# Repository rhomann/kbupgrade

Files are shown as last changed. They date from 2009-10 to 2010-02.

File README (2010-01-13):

|
| Keyboard Upgrade -- A generic open source firmware for
|                     homebrew computer keyboard controllers
|                     based on Atmel AVR microcontrollers.
|
| E-Mail: kbupgrade [at] gmx.net

_           _
=== What? ===

Have a PS/2 keyboard, but your brand new computer only supports USB?
Your PS/2-to-USB converter does its job only half-hearted?
Or do you have a keyboard never intended to work on a PC or Mac, but still want
to use it?

Then Keyboard Upgrade is for you! Build your own USB keyboard controller and
let the free Keyboard Upgrade firmware blow some life into it! Multiple
user-defined key maps can be uploaded to your controller and switched at any
time, turning your keyboard into a Dvorak or Colemak or any other layout
keyboard in hardware.

This open source firmware was designed for use on homebrew keyboard controllers
based on Atmel AVR microcontrollers--in particular, the ATMEGA series.
Currently, these keyboards are supported:

- IBM Model M (1391401 and compatibles)
- IBM Model M Mini (1392934 and compatibles)
- IBM M4-1 (without trackpoint)
- IBM Model M 122-key terminal keyboards (1390702 and compatibles)

Schematics are included. Support for new controller designs can be added fairly
easily by re-using a common set of source code files.

_                 _
=== Lawyer Mode ===

Copyright (C) 2009, 2010  Robert Homann.

The Keyboard Upgrade package is published under the terms of the
GNU General Public License Version 2.0 (or any later version),
GNU GPL for short.
See the file COPYING distributed with this package for the license terms.

Keyboard Upgrade makes use of the V-USB driver by
Objective Development Software GmbH.
Their driver is licensed under the terms of the GNU GPL as long as it is not
used commercially. For the exact license terms, please see

  http://www.obdev.at/products/vusb/

or the License.txt file in the directory containing the V-USB version shipped
with this software package.

Keyboard Upgrade also makes use of a modified version of the
BootloadHID USB boot loader by Objective Development Software GmbH.
BootloadHID is licensed under the terms of the GNU GPL as long as it is not
used commercially. For the exact license terms, please see

  http://www.obdev.at/products/vusb/bootloadhid.html
  http://www.obdev.at/products/vusb/

or the License.txt file in the directory containing the BootloadHID version
shipped with this software package.

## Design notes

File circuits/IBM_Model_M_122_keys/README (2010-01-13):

There are two circuit designs for IBM Model M 122-key terminal keyboards
in this directory: one with LED support (schematic.pdf), and a simpler
circuit without LEDs (simple.pdf). Both have been made with KiCad.

If your terminal keyboards does not have LEDs and you are not planning to
add some, it is recommended to stick with the simpler design, which is
also a bit cheaper than the LED-enabled version.

Jumper KM0 is on PD7 (pin 21) in the version with LED support, and on
PD3 (pin 17) in the simplified version.

Thanks to Specter_57 for providing the keyboard matrix information.

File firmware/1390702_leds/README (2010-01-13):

This is the firmware for IBM Model M 122-key terminal keyboards such as the IBM
1390702 with LED support. Take a look at the simplified version without LED
support if your keyboard doesn't have LEDs.

Suitable PCBs:
- Circuits are included (circuits/IBM_Model_M_122_keys/schematic.pdf).

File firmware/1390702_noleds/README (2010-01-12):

This is the firmware for IBM Model M 122-key terminal keyboards such as the IBM
1390702. Since the 1390702 does not have LEDs, there is no support for LEDs in
this firmware. There is another version with LED support, but the circuit for
that one is a bit more complicated.

Suitable PCBs:
- Circuits are included (circuits/IBM_Model_M_122_keys/simple.pdf).

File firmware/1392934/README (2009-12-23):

This is the firmware for IBM Model M Space Saving keyboards (also known as
"Space Saver" or "Model M Mini"). The firmware has been tested with a
1391472 and a 1392934.

Suitable PCBs:
- RUMP by Chris Lee (see http://mg8.org/rump/)
- Dulcimer by Ronald Schaten (see http://www.schatenseite.de/dulcimer.html)

Notes:
- Using this firmware instead of the version for the full-size version is
  advantageous because (1) the keyboard layout is sparser than on the full-size
  version, resulting in fewer chances for ghost keys; and (2) it gives you
  three more free I/O pins on the microcontroller (pins 18, 19, and 20) because
  there are no LEDs on the keyboard.
- If you plan to add LEDs to your Space Saver, consider using the firmware for
  the full-size version for a start. Adding LED support to the the version in
  this directory, however, is trivial and can be implemented upon request.
  Please contact the package author if you want this.

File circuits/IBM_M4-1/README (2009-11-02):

This is a circuit design for an IBM M4-1 keyboard (made with KiCad).

There are at least two different versions of the original PCB. Their dimensions
are very similar, but otherwise they are quite different. The problem is that
they have different connectors for attaching the keyboard matrix, LEDs, and
mouse buttons to the board, so you need to check your keyboard before building
the replacement PCB.

One version has a 19-pin connector and a 9-pin connector for the keyboard
matrix, plus a separate 4-pin connector for the LEDs, and another 4-pin
connecter for connecting the mouse buttons (only three traces used). Such a PCB
was found inside a 1379590 made by Lexmark (1994).

The other version has a 22-pin connector and a 13-pin connector for the
keyboard matrix. Three of the traces on the 22-pin connector are used for the
two mouse buttons and their GND, and four traces on the 13-pin connector are
used for the LEDs and their common GND (or +5V?). The PCB was found inside a
84G2524 made by Unicomp (1999), which also had an unused 4-pin connector
(mounted in the same place as the one for the mouse buttons on the Lexmark
model).

Jumper KM0 is on PD3 (pin 17).

Confirmed to work with the following keyboard models:

- 1379590 (Lexmark 1994)
- 84G2524 (Unicomp 1999)

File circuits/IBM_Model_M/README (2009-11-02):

There are two alternative circuit designs for IBM Model M keyboards
in this directory, suitable for various IBM models.

One of the designs comes from the RUMP project by Chris Lee
(see http://mg8.org/rump/), made with Eagle.
The other one comes from the Dulcimer project by Ronald Schaten
(see http://www.schatenseite.de/dulcimer.html), made with KiCad.

Jumper KM0 is on PD7 (pin 21).

Confirmed to work with the following keyboard models:

Classic, clicky Model M
- 1391401

Model M Mini (Space Saver)
- 1391472
- 1392934

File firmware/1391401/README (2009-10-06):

This is the firmware for IBM Model M keyboards. It has been tested with a
1391401, but may also work with other, similar IBM models.

Suitable PCBs:
- RUMP by Chris Lee (see http://mg8.org/rump/)
- Dulcimer by Ronald Schaten (see http://www.schatenseite.de/dulcimer.html)

Notes:
- When using RUMP, you may want to add three resistors and a 4-pin connector
  for the LEDs (see the Dulcimer PCB on how to connect).
- If you have a Model M Mini (aka Space Saver), consider using the firmware in
  the 1392934 directory instead.

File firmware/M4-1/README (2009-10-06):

This is the firmware for IBM M4-1 keyboards. It also works on the Unicomp
versions, at least on those with a blue IBM logo (tested on a 84G2524 model
from 1999).

Suitable PCBs:
- Circuit is included.

Notes:
- The circuit does not support the trackpoint yet, but is prepared to do so in
  the future. For this reason, port A on the ATMEGA is not utilized since the
  pins on this port can be configured as inputs for the ATMEGA's A/D
  converters.
- For an M4 (the one without the trackpoint) it should be possible to make a
  specialized version that does not attempt to use the trackpoint and mouse
  buttons. The circuit for that model would be a bit simpler since the pins
  used for trackpoint axes and mouse buttons could be used for the keyboard
  rows. This saves one shift register and 8 diodes (not much saved in terms of
  money, but in terms of PCB space).

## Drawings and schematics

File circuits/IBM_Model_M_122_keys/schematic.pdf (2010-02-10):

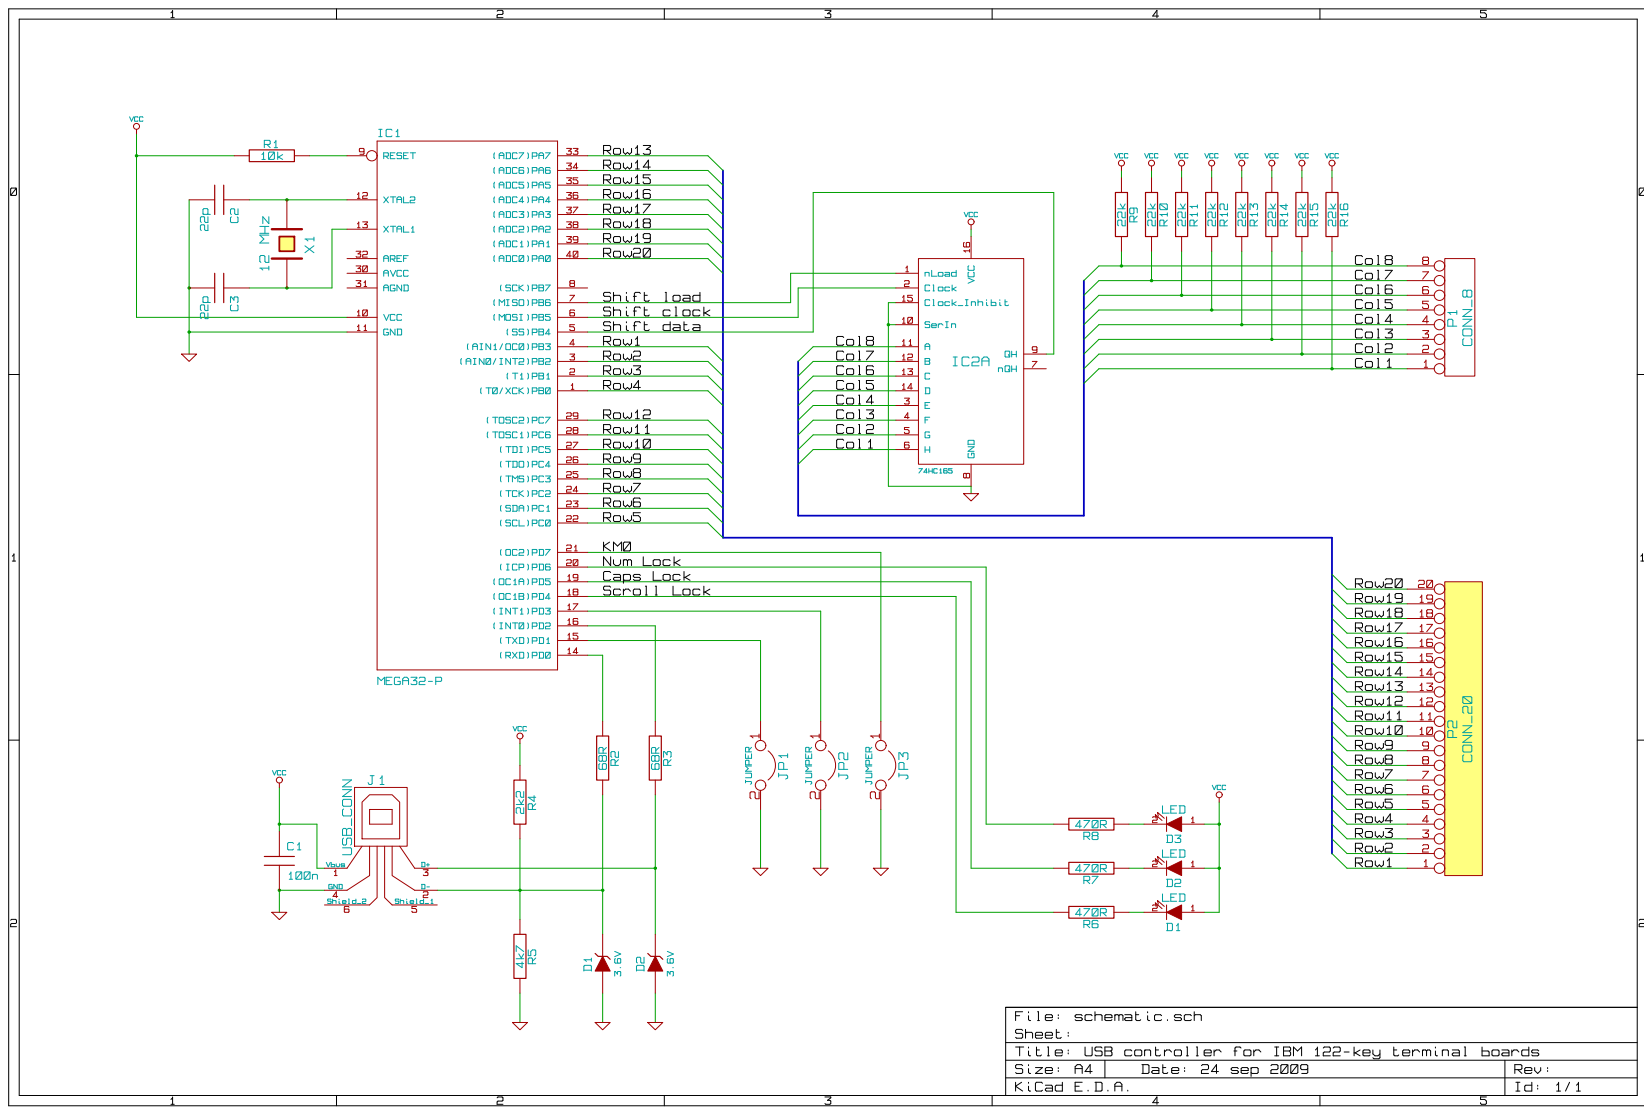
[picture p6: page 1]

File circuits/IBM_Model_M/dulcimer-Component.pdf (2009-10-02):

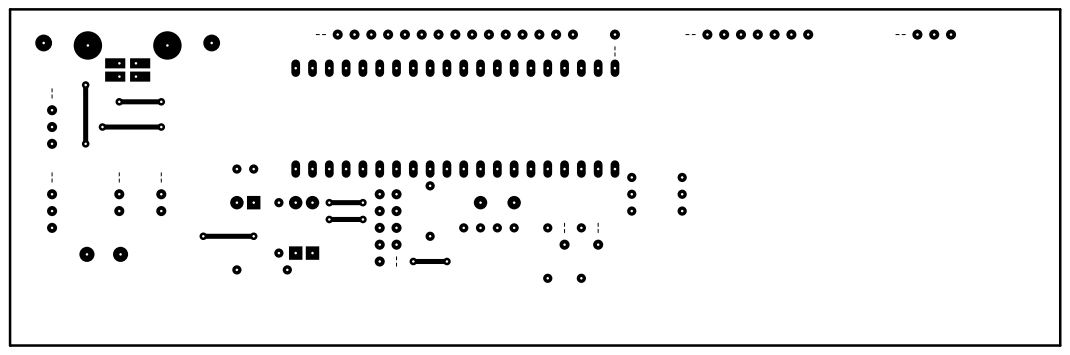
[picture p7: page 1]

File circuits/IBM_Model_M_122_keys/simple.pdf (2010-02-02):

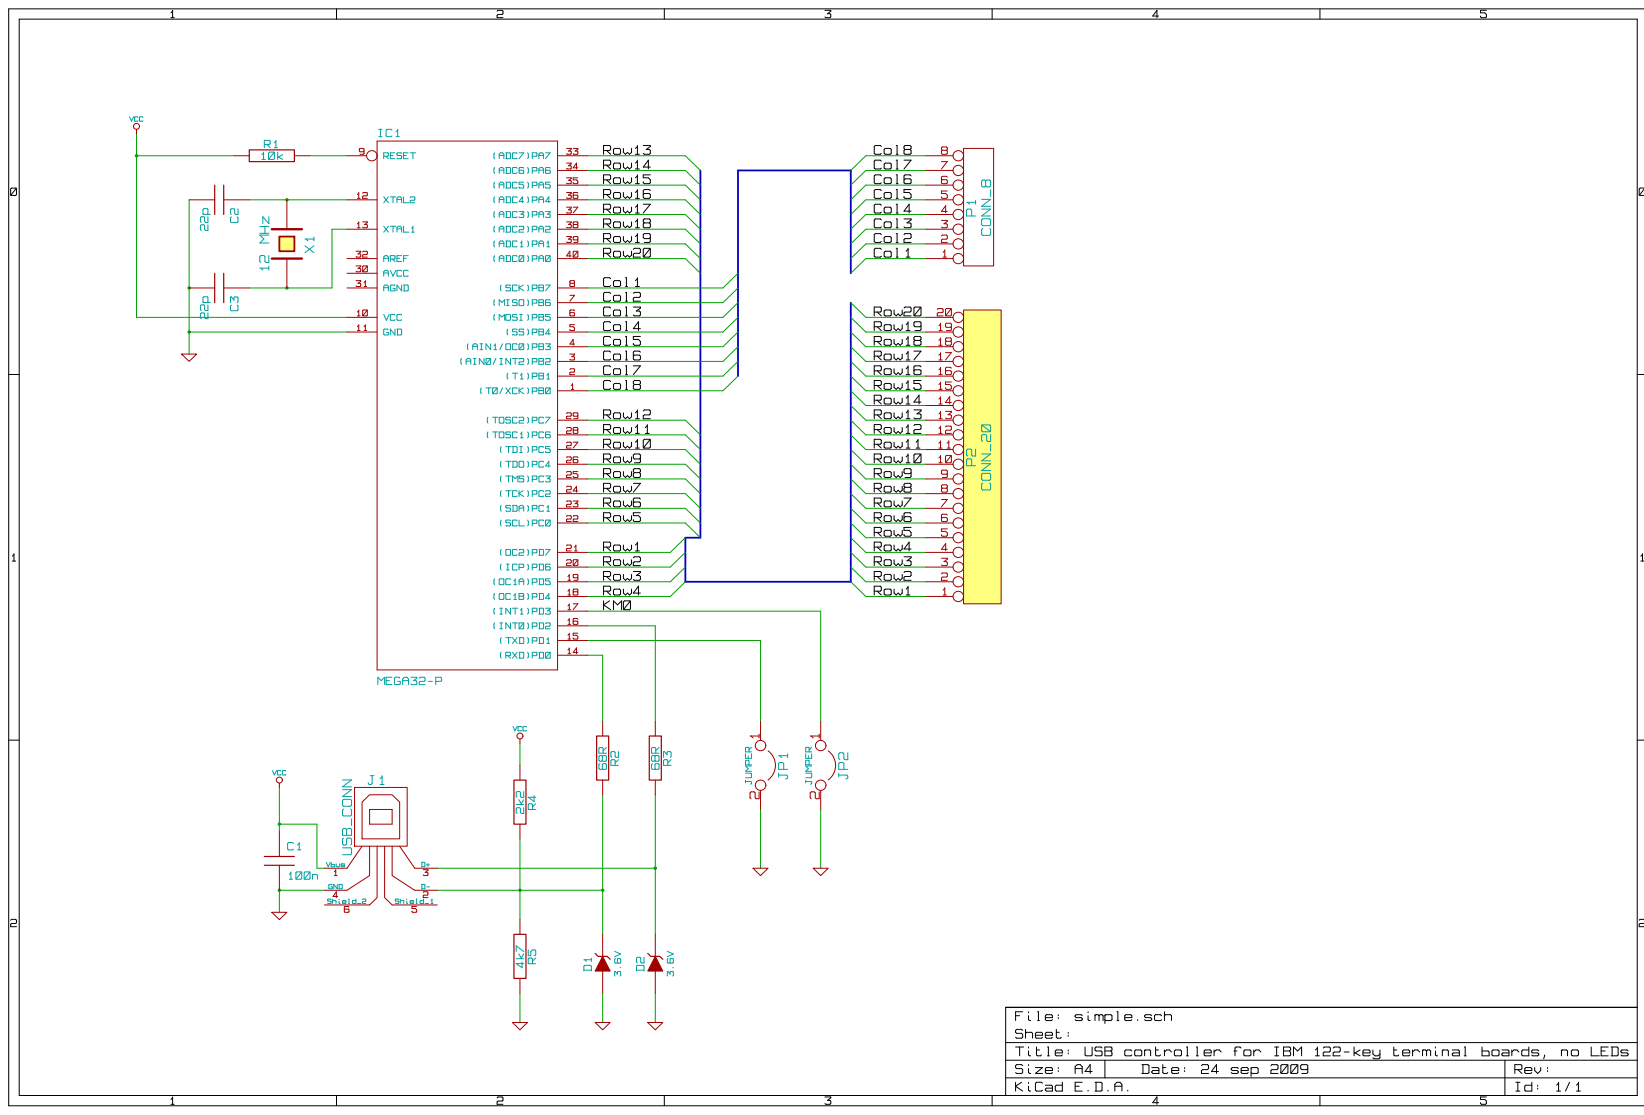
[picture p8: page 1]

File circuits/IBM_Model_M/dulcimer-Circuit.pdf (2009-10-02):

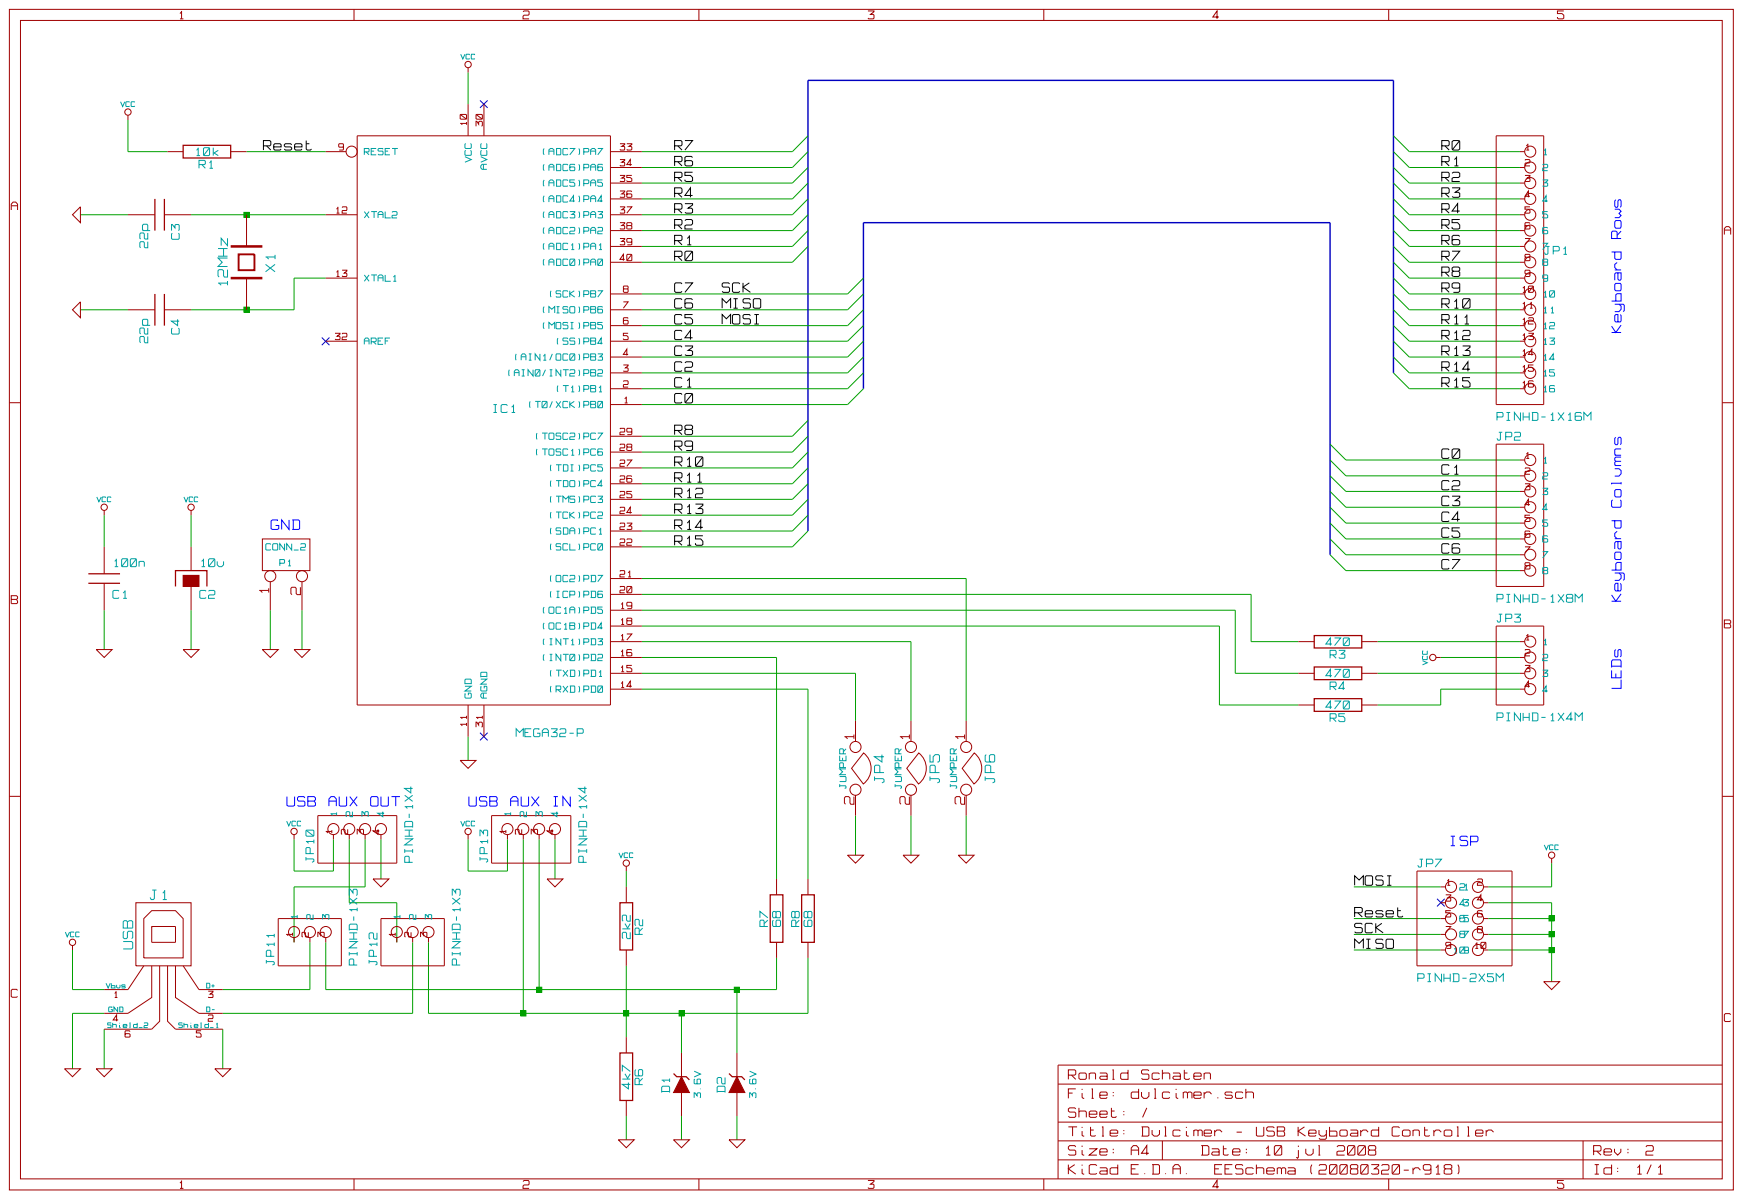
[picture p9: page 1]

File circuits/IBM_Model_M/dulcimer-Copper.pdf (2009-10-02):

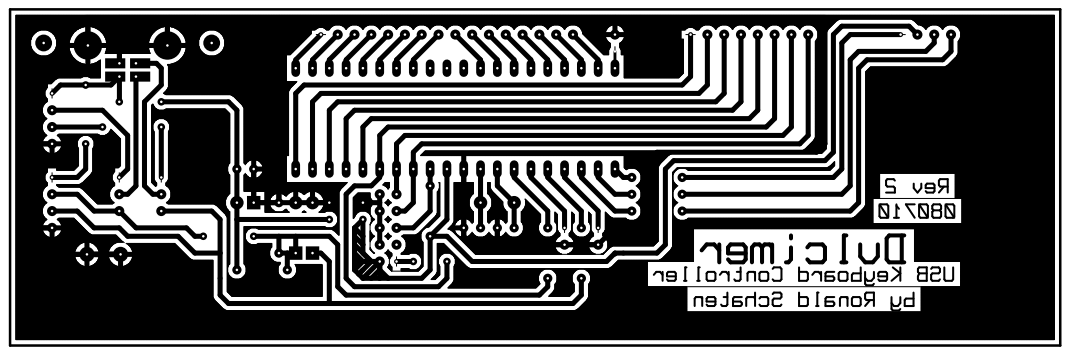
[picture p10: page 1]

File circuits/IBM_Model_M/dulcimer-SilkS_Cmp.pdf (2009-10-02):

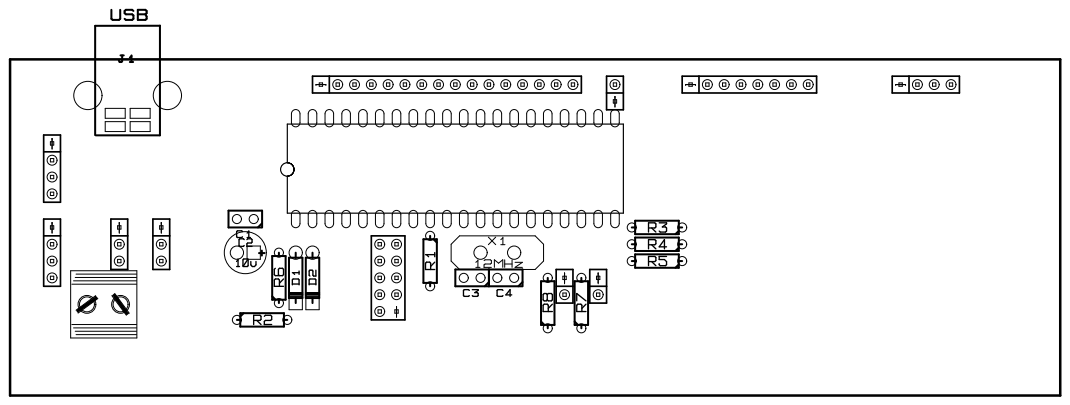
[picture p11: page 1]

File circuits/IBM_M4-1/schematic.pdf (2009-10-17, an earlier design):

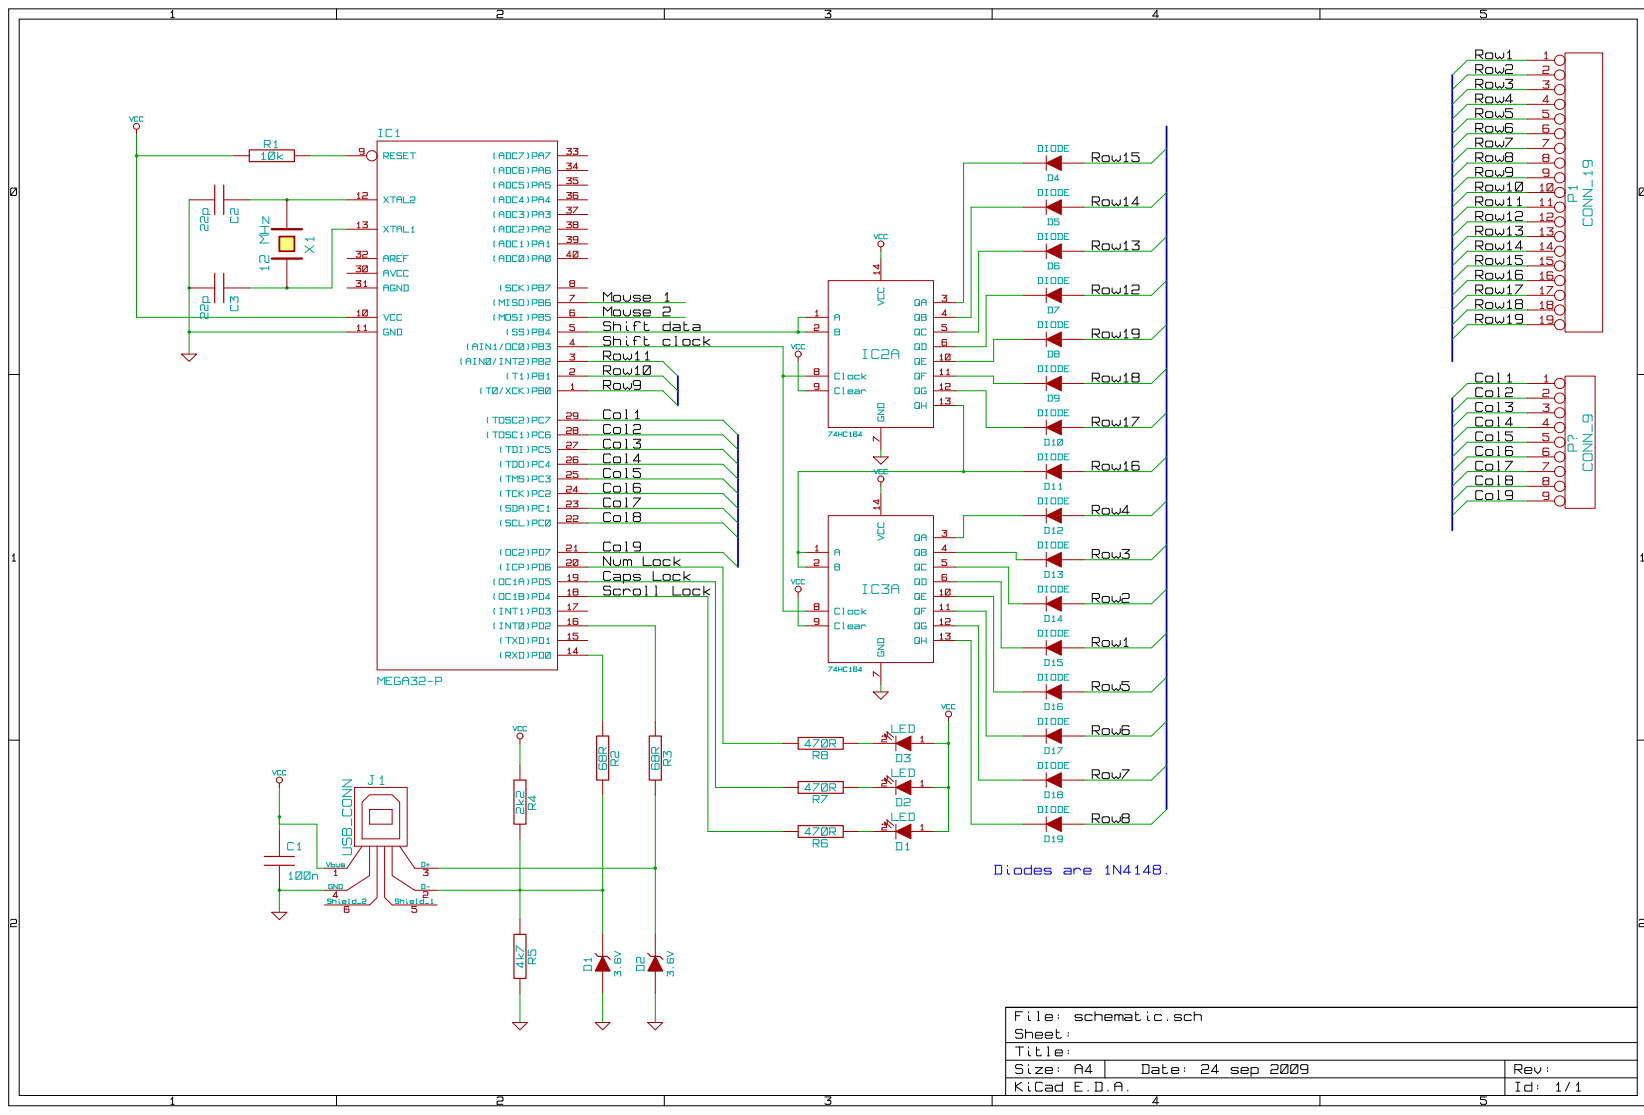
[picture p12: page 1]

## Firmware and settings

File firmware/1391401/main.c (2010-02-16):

/*
 * Keyboard Upgrade -- Firmware for homebrew computer keyboard controllers.
 * Copyright (C) 2009, 2010  Robert Homann
 *
 * This file is part of the Keyboard Upgrade package.
 *
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
 * You should have received a copy of the GNU General Public License
 * along with the Keyboard Upgrade package; if not, write to the
 * Free Software Foundation, Inc., 51 Franklin Street, Fifth Floor, Boston,
 * MA  02110-1301  USA
 */

#include <inttypes.h>
#include <string.h>
#include <avr/io.h>
#include <avr/interrupt.h>
#include <avr/pgmspace.h>
#include <avr/wdt.h>
#include <util/delay.h>

#define ROWS_PORT1  PORTA
#define ROWS_DDR1   DDRA

#define ROWS_PORT2  PORTC
#define ROWS_DDR2   DDRC

#define COLS_PORT   PORTB
#define COLS_DDR    DDRB
#define COLS_PIN    PINB

#define CFG_KEYMAP0_PORT  PIND
#define CFG_KEYMAP0_PIN   PIND7

#define LED_PORT        PORTD
#define LED_SCROLL_PIN  PIND4
#define LED_CAPS_PIN    PIND5
#define LED_NUM_PIN     PIND6
#include "leddefs.h"

#include "usbkeycodes.h"
#include "keyboard.h"
#include "stdmap.h"
#include "keymapdecoder.h"

static Map current_keymap;
static Columnstate column_valid_mask[NUM_OF_ROWS];
static Columnstate column_states[NUM_OF_ROWS];

#include "keymapdecode.c"
#define USB_SET_LED_STATE  set_led_state
#include "usbfuns.c"
#include "scanrows.c"
#include "processcolumns.c"
#include "scankeys.c"

static void setup(void)
{
  /* ports A through C are all inputs, enable pull-ups */
  PORTA=0xff;
  DDRA=0x00;
  PORTB=0xff;
  DDRB=0x00;
  PORTC=0xff;
  DDRC=0x00;

  /* port D has 3 inputs for jumper headers (pins 1, 3 ,7), 3 outputs for LED
   * grounds (pins 4, 5, 6), and two ports for USB data (pins 0 and 2) */
  PORTD=0xfa;  /* 1111 1010 */
  DDRD=0x70;   /* 0111 0000 */

  /* initialize USB stuff, force enumeration */
  usbInit();
  usbDeviceDisconnect();
  wdt_reset();

  /* flash the LEDs a bit */
  set_led_state(LED_NUM);
  _delay_ms(50);
  set_led_state(LED_CAPS);
  _delay_ms(50);
  set_led_state(LED_SCROLL);
  _delay_ms(50);
  set_led_state(0);

  set_current_keymap(get_current_keymap_index(0),1);

  _delay_ms(100);
  set_led_state(LED_SCROLL);
  _delay_ms(50);
  set_led_state(LED_CAPS);
  _delay_ms(50);
  set_led_state(LED_NUM);
  _delay_ms(50);
  set_led_state(0);

  /* that was a delay of at least 400 ms, now connect again */
  wdt_reset();
  usbDeviceConnect();

  /* set timer 0 to CTC mode, prescaling to 1024, and a value for the Output
   * Compare Register so that the timer triggers an interrupt every 16 ms */
#if F_CPU == 16*1000*1000
  OCR0=249;
#elif F_CPU == 12*1000*1000
  OCR0=187;
#else
#error Unsupported value of F_CPU.
#endif
  TCNT0=OCR0-1;
  TIMSK|=_BV(OCIE0);
  TCCR0=_BV(WGM01)|_BV(CS02)|_BV(CS00);

  sei();
}

volatile static uint8_t update_needed;

#include "standard_timer0_isr.c"
#include "standard_main.c"

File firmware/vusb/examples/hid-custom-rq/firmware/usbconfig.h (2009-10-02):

/* Name: usbconfig.h
 * Project: V-USB, virtual USB port for Atmel's(r) AVR(r) microcontrollers
 * Author: Christian Starkjohann
 * Creation Date: 2005-04-01
 * Tabsize: 4
 * Copyright: (c) 2005 by OBJECTIVE DEVELOPMENT Software GmbH
 * License: GNU GPL v2 (see License.txt), GNU GPL v3 or proprietary (CommercialLicense.txt)
 * This Revision: $Id: usbconfig-prototype.h 767 2009-08-22 11:39:22Z cs $
 */

#ifndef __usbconfig_h_included__
#define __usbconfig_h_included__

/*
General Description:
This file is an example configuration (with inline documentation) for the USB
driver. It configures V-USB for USB D+ connected to Port D bit 2 (which is
also hardware interrupt 0 on many devices) and USB D- to Port D bit 4. You may
wire the lines to any other port, as long as D+ is also wired to INT0 (or any
other hardware interrupt, as long as it is the highest level interrupt, see
section at the end of this file).
*/

/* ---------------------------- Hardware Config ---------------------------- */

#define USB_CFG_IOPORTNAME      D
/* This is the port where the USB bus is connected. When you configure it to
 * "B", the registers PORTB, PINB and DDRB will be used.
 */
#define USB_CFG_DMINUS_BIT      4
/* This is the bit number in USB_CFG_IOPORT where the USB D- line is connected.
 * This may be any bit in the port.
 */
#define USB_CFG_DPLUS_BIT       2
/* This is the bit number in USB_CFG_IOPORT where the USB D+ line is connected.
 * This may be any bit in the port. Please note that D+ must also be connected
 * to interrupt pin INT0! [You can also use other interrupts, see section
 * "Optional MCU Description" below, or you can connect D- to the interrupt, as
 * it is required if you use the USB_COUNT_SOF feature. If you use D- for the
 * interrupt, the USB interrupt will also be triggered at Start-Of-Frame
 * markers every millisecond.]
 */
#define USB_CFG_CLOCK_KHZ       (F_CPU/1000)
/* Clock rate of the AVR in kHz. Legal values are 12000, 12800, 15000, 16000,
 * 16500 and 20000. The 12.8 MHz and 16.5 MHz versions of the code require no
 * crystal, they tolerate +/- 1% deviation from the nominal frequency. All
 * other rates require a precision of 2000 ppm and thus a crystal!
 * Default if not specified: 12 MHz
 */
#define USB_CFG_CHECK_CRC       0
/* Define this to 1 if you want that the driver checks integrity of incoming
 * data packets (CRC checks). CRC checks cost quite a bit of code size and are
 * currently only available for 18 MHz crystal clock. You must choose
 * USB_CFG_CLOCK_KHZ = 18000 if you enable this option.
 */

/* ----------------------- Optional Hardware Config ------------------------ */

/* #define USB_CFG_PULLUP_IOPORTNAME   D */
/* If you connect the 1.5k pullup resistor from D- to a port pin instead of
 * V+, you can connect and disconnect the device from firmware by calling
 * the macros usbDeviceConnect() and usbDeviceDisconnect() (see usbdrv.h).
 * This constant defines the port on which the pullup resistor is connected.
 */
/* #define USB_CFG_PULLUP_BIT          4 */
/* This constant defines the bit number in USB_CFG_PULLUP_IOPORT (defined
 * above) where the 1.5k pullup resistor is connected. See description
 * above for details.
 */

/* --------------------------- Functional Range ---------------------------- */
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

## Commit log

2009-10-02 First commit on Github.
    [dulcimer.brd, dulcimer.sch, rump.sch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]
2009-10-04 Row/column permutations on separate files.
    Permutations of matrix row and columns may be specified on external files now,
    in addition to those specified in the matrix definition files. The reason for
    this is that different PCB designs for the same keyboard may require different
    rearrangements, so the permutations are actually PCB-, not keyboard-specific.
    Use option -p to give a file containing the permutations.
    Former option -p (don't put generated definitions into RAM) has now -P.
2009-10-04 "make dist" works now.
    [tiny45-rc.sch, with-series-diodes.sch, with-vreg.sch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]
2009-10-04 Script procmatrix.py works with Python 3 now.
    A few small tweaks were needed to get procmatrix.py run with Python 3. It still
    runs fine in 2.6 (tested with 2.6.2).
    The configure script now checks the version of the detected Python interpreter,
    compares it via AS_VERSION_COMPARE, and throws an error in case it's older than
    2.6.
2009-10-06 Fixed M4-1 firmware and matrix definition.
    Also tweaked the procmatrix.py script a bit.
    [main.c, pindefs.h]
2009-10-06 Added schematic for M4-1 controller (incomplete).
    The schematic does not include trackpoint support yet.
    [pcb.sch]
2009-10-06 Added missing license header.
    [pindefs.h]
2009-10-06 Fixed boot loader for the M4-1.
    The boot loader works now, and it is activated by holding down the Escape key
    just like on the Model M.
    [pindefs.h]
2009-10-07 Debouncing can be disabled per firmware image.
    If a keyboard is equipped with non-bouncing switches, then the number of
    debounce iterations (DEBOUNCE_ITERATIONS) may now be set to 1 to entirely
    disable software debouncing.
    Also, the default number of iterations for debouncing (if DEBOUNCE_ITERATIONS
    is undefined) has been lowered from 10 to 5 as I didn't experience bouncing
    effects with that value. When setting the number of iterations to 3, however, I
    had occasional double key activations, so 5 seems fine for now.
2009-10-07 Partial builds if some tools or libs are missing.
    The configure script does not error out anymore if, i.e., the cross compiler or
    Python are not found; instead, a warning is printed. If a certain tool or
    library is missing that is required to build a some part of the package, then
    no attempt will be made to build that part. For instance, if the cross compiler
    was not found, then the firmware images cannot be built, but this does not
    prevent us from building the boot loader command line tool.
    In addition, all warnings issued by configure, if any, will be repeated at the
    end, after the configure script has done its main tasks.
2009-10-16 Setting more USB stuff from within configure.ac.
    USB configuration is also in config.h now, so that programs know which vendor
    ID, device ID, etc. to look for.
2009-10-17 Attaching to driver only if was attached before.
2009-10-17 Renamed M4-1 schematic, and made it a bit nicer.
    [schematic.sch]
2009-10-24 Communication with keyboard via control requests.
    We use "vender-specific control requests" to talk to the keyboards.
    Currently, the hardware information can be read from the keyboard (number of
    keys etc.). Key maps can be read, too. More requests are defined in
    usbrequests.h already, but not yet implemented in the firmware.
    The command line tool displays keyboard information when run without arguments.
    All key maps can be downloaded from the keyboard and written to files.
2009-10-27 Scroll Lock enables command mode.
    Pressing Scroll Lock and releasing it again (and after all other keys have been
    released, too) activates command mode. The Scroll Lock LED is toggled to
    indicate that command mode is activated, and the next key is interpreted as a
    command. The keyboard returns to normal mode after executing the command.
    Neither Scroll Lock nor the command key are reported to the host, making these
    keystrokes completely invisible to applications.
    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
2009-10-28 Key map selection is software-only now.
    As before, key maps can be selected using Scroll Lock followed by a digit key,
    but the selection is stored in EEPROM now. Thus, the key map setting is
    persistently stored and survives resets and power-offs. As a result, the config
    jumpers are not "wasted" for key map selection anymore and can be used for
    something else.
    Now, one of the jumpers is used to lock the key map to index 0, which is
    primarily useful to avoid bricking the keyboard in case broken key map data was
    uploaded to the keyboard and activated there.
    [main.c]
2009-11-01 Introduced "official" way to abort command mode.
    Escape leaves command mode without doing anything. So does any other
    non-command key, but we need a failsafe way.
    Symbols CMDMODE_ENTER_KEY and CMDMODE_ABORT_KEY are defined to Scroll
    Lock and Escape; these are used instead of hardcoded keycodes now.
    [commandmode.h]
2009-11-02 Pressing Scroll Lock in command mode emits SL.
    When pressing Scroll Lock in command mode, the keyboard returns to normal mode
    as before, but also emits a Scroll Lock key stroke. Thus, Scroll Lock can be
    seen by KVM switches (hit SL four times if it needs to see SL twice), and also
    by the host for the few programs that actually react to this key.
2010-01-05 Putting AVR fuse values into firmware zip files.
    The values of the AVR fuses are written to the generated file_id.diz
    files. When programming the AVR for the first time, these values must
    be used to program its fuses.
    Also bumped the package version to 0.2.1.
2010-01-12 Initial support for the 1390702 terminal keyboard.
    This version does not support LEDs because the keyboard matrix is
    quite big (20x8), so there are only 2 pins left (used for config
    jumpers). That's OK for original IBM 1390702 keyboards because they
    don't have LEDs anyway.
    The scanrows.c code needed an upgrade to support more than 16 rows. If
    there are more than 16 rows, the including source file must define
    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
2010-01-13 Support for 1390702 terminal keyboard with LEDs.
    This is the firmware for a more complicated version of the 122-key
    keyboard controller that makes use of a shift register to extend the
    I/O space. There are even two spare pins now.
2010-01-13 Circuit diagrams for 122-key terminal keyboards.
    [schematic.sch, simple.sch]
2010-01-13 Added KiCad reference.
2010-02-02 Model M 122-key keyboard uses a PISO register.
    The schematic has been changed so to make use of an 8-bit register
    that is used to read the column lines. Firmware gets simpler this way.
    [schematic.sch]
2010-02-02 Rearranged some of the rows; nicer schematic.
    [simple.sch]
2010-02-02 Rewritten LED-enabled 122-key Model M firmware.
    The firmware for the 1390702 with LED support has been rewritten to
    work with the new schematic (commit b932b23). It has been tested on
    breadboard and works fine.
    Code for PISO shift registers has been added to shiftreg.c.
    The code in scanrows.c had to be extended so to allow for alternative
    ways for reading the column lines (i.e., not reading the values
    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
2010-02-02 Added resistor values to schematic.
    [schematic.sch]
2010-02-02 Added missing lines to schematic.
    [simple.sch]
2010-02-02 Fixed non-LED 122-key boot loader, tested.
2010-02-10 Minor changes to 122-key schematic.
    Pull-up resistor values changed from 20k to 22k, which is a more
    common value.
    [schematic.sch]
2010-02-16 Fixed memory corruption in case of USB init error.
2010-02-16 F1 through F10 can be used for key map switching.
2010-03-12 Implemented secondary function key.
    Two function keys can be programmed now, allowing to switch directly
    to two different key maps. In addition, both function keys can be
    pressed together so to switch to yet another key map, giving access to
    three temporarily selectable key maps.

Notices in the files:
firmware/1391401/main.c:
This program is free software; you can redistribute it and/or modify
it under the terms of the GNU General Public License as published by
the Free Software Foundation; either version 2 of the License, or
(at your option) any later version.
